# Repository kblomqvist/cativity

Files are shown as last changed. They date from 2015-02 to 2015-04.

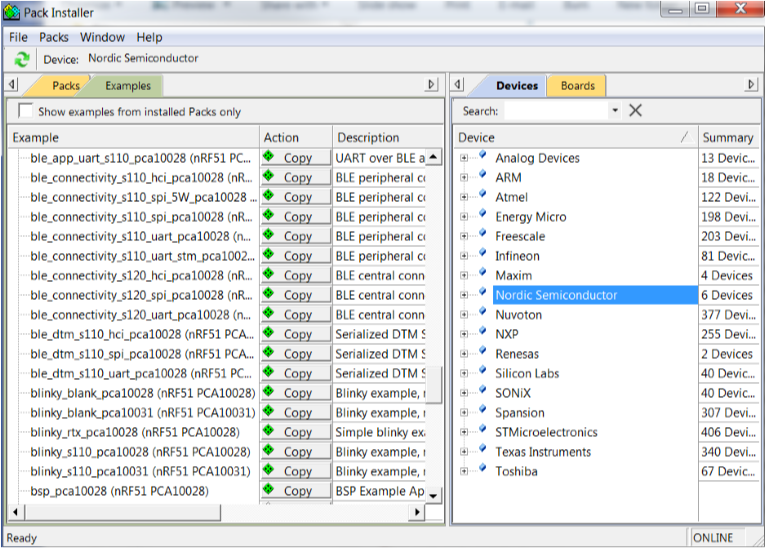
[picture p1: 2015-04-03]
sw/nrf51/documentation/s110/html/pack_installer.png

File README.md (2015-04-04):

# Cativity

## SW Usage

nRF51 s110 softdevice is used by default (see `Makefile.project`), so at first you need to flash the softdevice binary:

```
make softdevice
```

The above command erase the chip and programs the softdevice binary appropriately. Now compile the user program and flash/upload it:

```
make
make upload
```

## Example/Test SW

Use `segger.py` script directly to flash `.bin` binaries.

### Proximity/RSSI test

```
export BUILD_PATH=./build
export JLINK_PATH=/usr/bin
python segger.py flash examples/ble_peripheral_proximity_nrf518222_xxaa_s110.bin 0x18000
```

## HW Errata
- ANT footprint
- QFN thermal pad paste mask too large
- Remove paste mask from programming pads
- 2u2 pad size too large, should be 0402

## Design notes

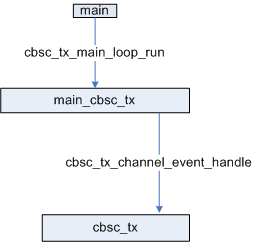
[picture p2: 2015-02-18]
sw/nrf51/documentation/s210/html/bicycle_speed_and_cadence_sensor_design.png

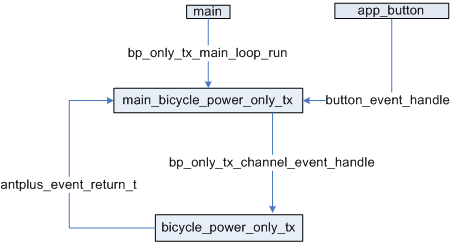
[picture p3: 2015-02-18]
sw/nrf51/documentation/s210/html/bicycle_power_only_tx_design.png

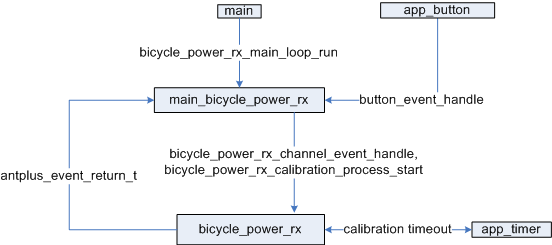
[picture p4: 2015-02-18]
sw/nrf51/documentation/s210/html/bicycle_power_rx_design.png

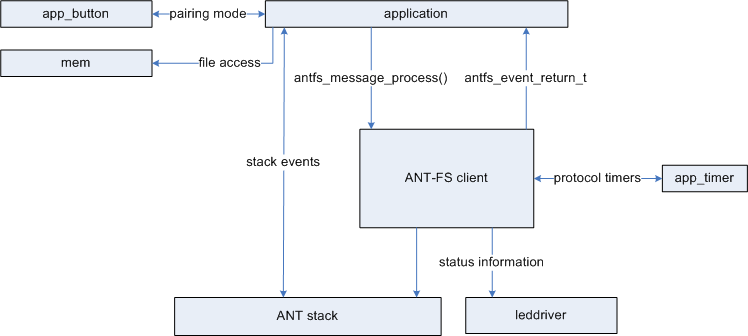
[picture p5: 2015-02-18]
sw/nrf51/documentation/s210/html/ant_fs_embedded_client_device_simulator_architecture.png

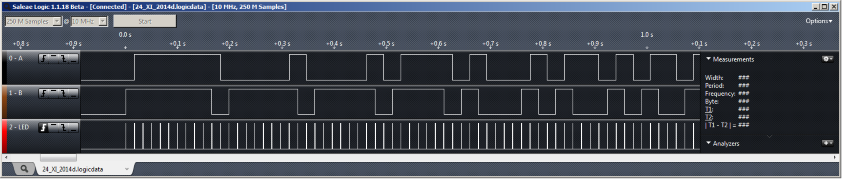
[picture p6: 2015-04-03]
sw/nrf51/documentation/s110/html/qdec_example.png

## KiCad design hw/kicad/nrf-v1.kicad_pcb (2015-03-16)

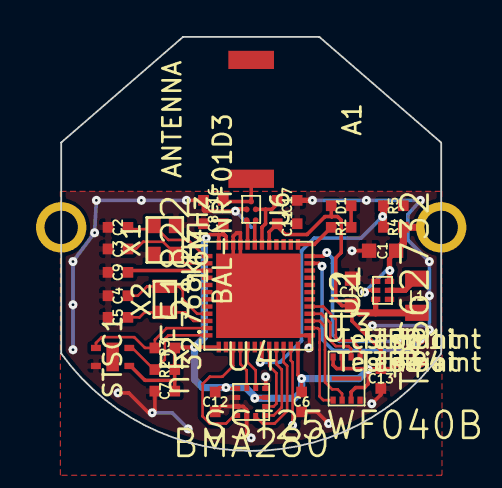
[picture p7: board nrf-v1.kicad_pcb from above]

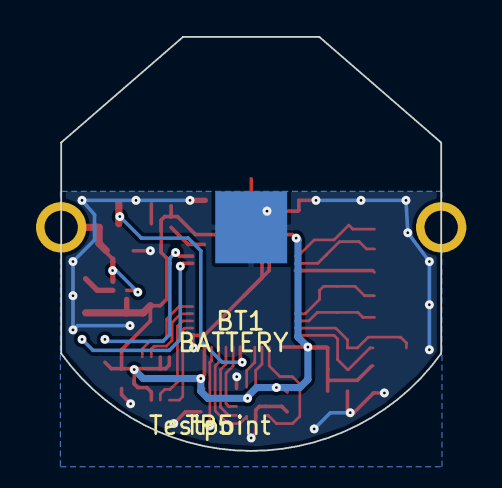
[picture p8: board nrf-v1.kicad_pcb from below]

Board: 2 copper layers, 21.1 x 23.0 mm, 37 parts (2 on the bottom side), 31 nets.

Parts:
A1: ANTENNA; AntennaFactor-ANT-2.4-CHP
BT1: BATTERY; Keystone-3003
C1, C10: 2u2; IPC-0603
C2, C3, C4, C5: 12p; IPC-0402
C6, C7, C9, C12, C13: 100n; IPC-0402
C8: 1n; IPC-0402
C11: 47n; IPC-0402
C16, C17: DNP; IPC-0402
D1: LED; IPC-0402
L1: INDUCTOR_SMALL; IPC-0805
R1: R; IPC-0402
R2, R3: 4k7; IPC-0402
R4: 100k; IPC-0402
R5: 120k; IPC-0402
TP1, TP2, TP3, TP4, TP5: Testpoint; TP_0.6
U1: TPS62732; TI-USON-6_(1.45x1.00)
U2: nRF51822; NordicSemi-QFN-48_(6.00x6.00)
U3: SST25WF040B; Microchip-USON-8_(2.00x3.00)
U4: BMA280; Bosch-LGA-12_(2.00x2.00)
U5: STSC1; Sensirion-DFN-4_(2.0x2.0)
U6: BAL-NRF01D3; ST-BGA-5_(1.50x1.00)
X1: 16MHz; Abracon-ABM10
X2: 32.768kHz; Abracon-ABS06

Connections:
+BATT: BT1.1, C1.1, R4.1, U1.3, U1.5
GND: BT1.2, C1.2, C2.2, C3.2, C4.2, C5.2, C6.2, C7.2, C8.2, C9.2, C10.2, C11.2, C12.2, C13.2, C16.2, C17.2, R5.2, TP4.1, U1.4, U2.13, U2.33, U2.34, U2.PAD, U3.4, U4.4, U4.8, U4.9, U4.11, U5.4, U6.A2, X1.2, X1.4
unnamed: A1.1, C16.1, U6.B1
unnamed: C2.1, U2.37, X1.1
unnamed: C3.1, U2.38, X1.3
unnamed: C4.1, U2.45, X2.1
unnamed: C5.1, U2.46, X2.2
unnamed: C9.1, U2.39
unnamed: C17.1, U2.30, U6.C2
unnamed: D1.2, R1.1
unnamed: L1.1, U1.2
unnamed: U2.31, U6.C3
unnamed: U2.32, U6.A3
VDD: C6.1, C7.1, C8.1, C10.1, C11.1, C12.1, C13.1, D1.1, L1.2, R2.1, R3.1, TP3.1, U1.6, U2.1, U2.12, U2.29, U2.35, U2.36, U3.3, U3.7, U3.8, U4.3, U4.7, U5.1
acc_int1: U2.5, U4.5
acc_int2: U2.4, U4.6
bootloader: TP5.1, U2.11
spi0_cs_n: U2.14, U3.1
spi0_miso: U2.15, U3.2
spi0_mosi: U2.17, U3.5
spi0_sck: U2.16, U3.6
spi1_cs_n: U2.3, U4.10
spi1_miso: U2.9, U4.1
spi1_mosi: U2.8, U4.2
spi1_sck: U2.10, U4.12
swclk: TP2.1, U2.24
swdio: TP1.1, U2.23
twi_scl: R2.2, U2.48, U5.2
twi_sda: R3.2, U2.47, U5.3
vbat_adc: R4.2, R5.1, U2.7
~led: R1.2, U2.25

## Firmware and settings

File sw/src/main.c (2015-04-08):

#include <stdbool.h>
#include <stdint.h>
#include "nrf_delay.h"
#include "nrf_gpio.h"

#include "twi_master.h"

bool stsc1_detect(void)
{
	const uint8_t address = 0x4A << 1;
	
	// check id
	uint8_t read_id_reg_cmd[2] = {0xef, 0xc8};
	uint8_t resp[3];
	
	if (!twi_master_transfer(address, read_id_reg_cmd, 2, TWI_ISSUE_STOP))
		return false; // failed
	
	if (!twi_master_transfer(address | TWI_READ_BIT, resp, sizeof(resp), TWI_ISSUE_STOP))
		return false; // failed
	
	if ((resp[1] & 0x3f) != 0b000111)
		return false; // wrong product code
	
	return true;
}

int main(void){
	nrf_gpio_cfg_output(17);
	
	twi_master_init();

	bool temp_present = stsc1_detect();

	while(1){
		nrf_gpio_pin_toggle(17);

		if (temp_present)
			nrf_delay_ms(500);
		else
			nrf_delay_ms(200);
	}
}

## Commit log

2015-02-18 Add KiCad design files
    [nrf-v1.sch]
2015-02-18 Add BMA280,SI7053 symbols
    [nrf-v1.sch]
2015-02-18 Add TPS62732 symbol
    [nrf-v1.sch]
2015-02-19 Add SST25WF040B symbol
    [nrf-v1.sch]
2015-02-19 Add footprint library
2015-02-19 Initial layout
    [nrf-v1.kicad_pcb]
2015-02-19 Add crystals
    [nrf-v1.kicad_pcb, nrf-v1.sch]
2015-02-19 Change coin cell holder
    From 25mm to 20mm
    [nrf-v1.kicad_pcb]
2015-02-20 Component placement draft
    [nrf-v1.kicad_pcb, nrf-v1.sch]
2015-02-21 Updated coin cell holder
    [nrf-v1.kicad_pcb, nrf-v1.sch]
2015-02-24 Update schematics
    [nrf-v1.sch]
2015-02-24 Add PCB shape
    [nrf-v1.kicad_pcb]
2015-02-28 Fix padding between pcb and enclosure
    Ready to pull enclosure
2015-02-28 Sketch bottom part of the enclosure
    Coin cell clip cannot be used for attaching the board to bottom side
    because otherwise it would become extremely thick.
2015-03-01 Add 0402 footprint
    [nrf-v1.sch]
2015-03-01 Replace temp sensor
    [nrf-v1.kicad_pcb, nrf-v1.sch]
2015-03-15 PCB ready for 1st review
    [nrf-v1.kicad_pcb, nrf-v1.sch]
2015-03-16 Add schematics as PDF
2015-03-16 Update schematic pdf
2015-03-16 Balun: enlarge solder paste openings
2015-03-16 Battery holder: enlarge annular rings
2015-03-16 Update layout
    - footprint updates
    - added gnd vias
    - polygon fills (max'd out)
    [nrf-v1.kicad_pcb, nrf-v1.sch]
